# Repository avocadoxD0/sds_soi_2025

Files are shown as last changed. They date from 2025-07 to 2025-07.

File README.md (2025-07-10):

# Reaction Wheel Attitude Control System

This repository contains the complete design and development of a single-axis reaction wheel system for satellite attitude stabilization. The project brings together mechanical modeling, circuit design, and embedded control to achieve angular velocity detumbling.

The system is built around a reaction wheel mechanism, controlled using real-time feedback from an onboard IMU. All major subsystems including mechanical structure, electronics, and control algorithm are developed in coordination to function as a unified, self-contained system.

This repository serves as a consolidated record of the entire design process, including CAD models, PCB design files, and control code.

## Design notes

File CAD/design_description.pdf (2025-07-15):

## Design Decisions - Reaction Wheel Module

This reaction wheel system was designed to be compact, 3D-printable, and modular, suitable for integration into a CubeSat-class spacecraft. The following key design decisions were made:

- Volume Optimization:
The entire assembly was constrained to fit within a 60 mm x 60 mm x 69 mm housing, keeping the total volume under the specified 250 cm³
limit. This ensured compatibility with satellite form factor requirements.
- Flywheel Geometry:
A 50 mm diameter flywheel with 8 mm thickness was selected to maximize moment of inertia while ensuring adequate clearance within the enclosure. The flywheel was designed for uniform mass distribution and rotational balance.
- Gear-Based Torque Transmission:
A gear system was used between the DC motor and the flywheel shaft. A 10-tooth external gear drives a 24-tooth internal gear, resulting in torque amplification, ideal for generating controlled angular momentum.
- Motor Mounting and Axis Offset:
The DC motor is mounted 3.5 mm off-center to accommodate the gear mesh with the internal gear. The motor mount was custom-modeled to ensure tight fitment and structural rigidity, while allowing for proper shaft alignment.
- Material Selection:
All components were modeled using ABS plastic (as defined in SolidWorks), representing realistic 3D-printing material properties. This allowed accurate mass and inertia calculations throughout the design process.
- Printability Focus:
Every part was intentionally designed with minimal overhangs, greatly reducing the need for support structures during 3D printing. All geometries are primarily clean and self-supporting, ensuring straightforward and efficient fabrication.

This design prioritizes balance, printability, and functional performance, laying the groundwork for reliable attitude control when paired with embedded control logic and sensing systems.

## STL Orientation Note

The exported STL files are oriented in the Z-up direction, as defined during design in Solid-Works. While this orientation is consistent in both the CAD environment and GitHub STL previews, it is not necessarily optimized for 3D printing. Prior to printing, each part should be reoriented appropriately within slicing software such as Ultimaker Cura to ensure flat base surfaces and support-free printing. This adjustment is standard practice and ensures better printability without altering the model geometry.

1

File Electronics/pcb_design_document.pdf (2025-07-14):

# PCB Design Document

## Basics

The satellite power supply is assumed to be of 28 V. A buck converter has been used to

convert the voltage level to be within the acceptable limit for the choice of microcontroller

Arduino Nano. The LM2596S – 5 is used to obtain a 5 V DC supply from the satellite

power supply and this is used to power the Arduino Nano. The microcontroller has been

programmed with the control logic to operate the motor driver DRV8833PW.

## Further Details on Choice of Components

The motor driver DRV8833PW was selected to run a DC motor which was decided to

be the actuator. This uses MOSFETs which are much more efficient compared to the alternative Bipolar Junction Transistors (BJTs). They consume significantly less power

and is an optimal choice since power consumption and the resultant temperature rise is

of concern.

## PCB Layout

The area covered is much less than the limit of 10cm x 10cm. The components have been

arranged to aid in heat dissipation. There is a copper layer that acts as ground plane.

This also aids in heat dissipation helping to maintain the temperature in a sustainable

range by preventing overheating. The board will have 4 layers. This will help reduce the

lengths of traces as well. The placement of traces has been done to achieve a balance

between trace length and interference. There are also heat sinks for both the power

converter LM2596S - 5 as well as the motor driver DRV8833PW.

1

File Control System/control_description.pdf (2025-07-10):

## Reaction Wheel Control Code Description

### 1. Microcontroller

The control code is written for the Arduino Nano microcontroller. It communicates with the IMU over I²C and generates PWM signals to drive the motor through a DRV8833 H-bridge motor driver.

### 2. Sensors and Actuators

- Sensor: MPU9250 (9-axis IMU), using only the gyroscope’s Z-axis angular velocity for control feedback.
- Actuator: DC motor connected to a flywheel via an internal gear. The motor is controlled using the DRV8833 dual H-bridge motor driver, with PWM signals applied directly to the IN1 and IN2 pins.

### 3. Control System Behavior

The control system implements a PID controller to reduce angular velocity about the Z-axis. The current angular velocity is measured from the MPU9250 and compared to a small target threshold (approximately 0.5°/s, or 0.0087 rad/s). The resulting error is processed through the PID controller to determine the motor’s speed and direction.

### Behavior Under Different Conditions

- When the system starts with high angular velocity, the motor spins the flywheel in the opposite direction to apply counter-torque and reduce spin.
- As the angular velocity approaches the target value, the PWM duty cycle decreases and the motor slows down.
- Once the target is nearly reached, the system stabilizes and stops applying further corrections.

1

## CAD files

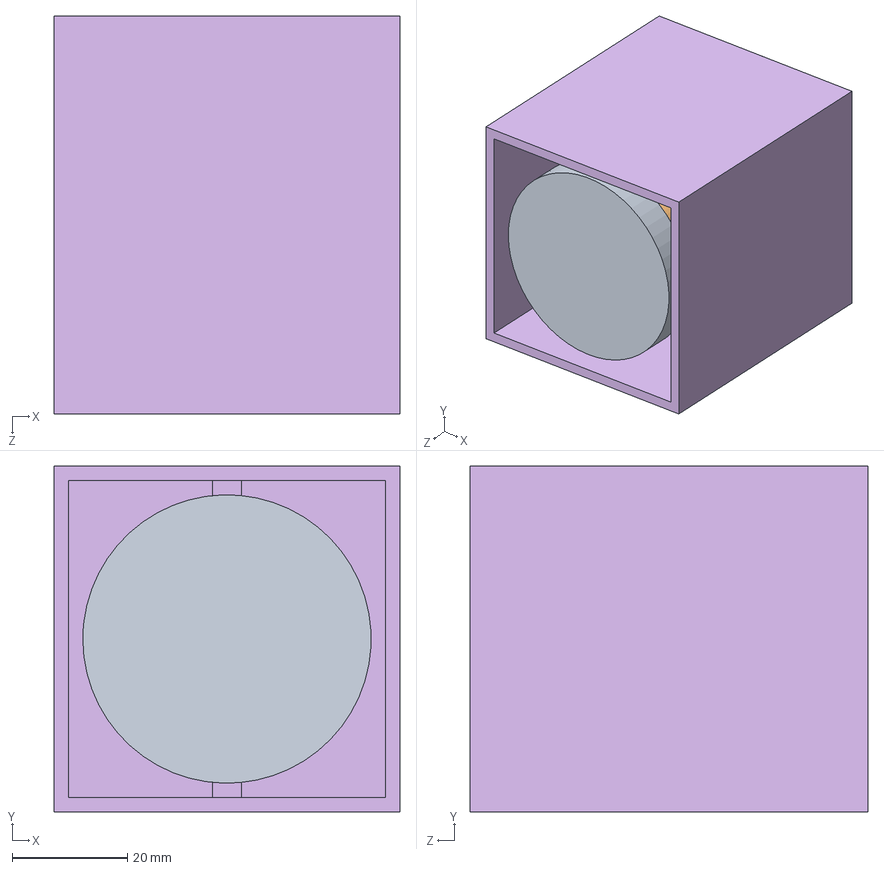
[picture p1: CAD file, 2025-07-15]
CAD/SOLIDWORKS_src/final assembly.SLDASM
60.0 x 60.0 x 69.0 mm
outer housing
motor mount
dc motor
motor gear
shaft
flywheel

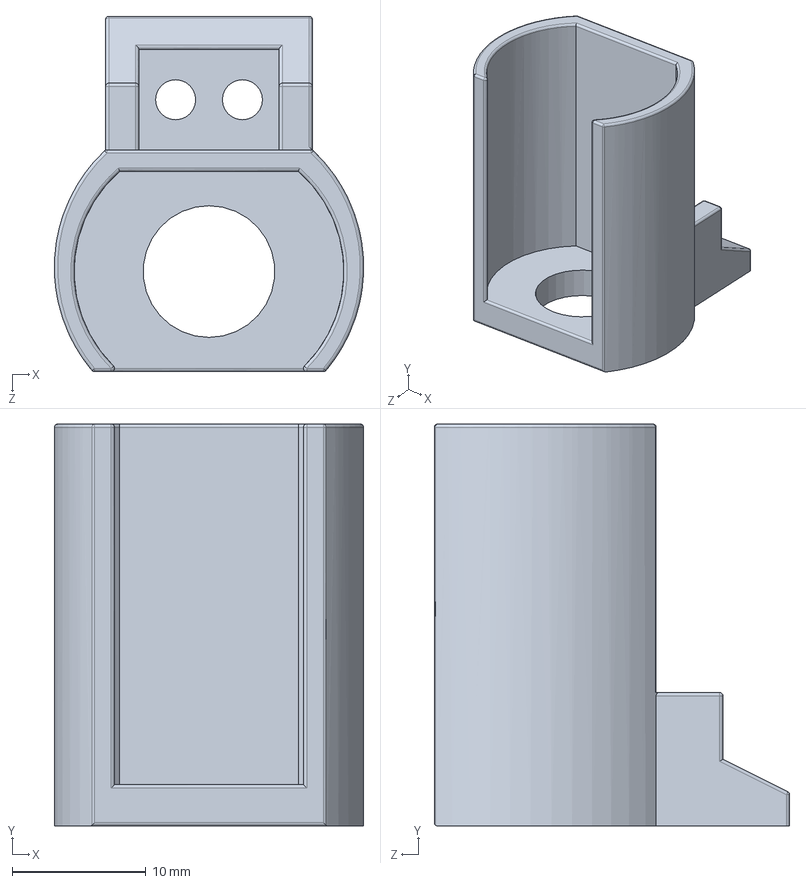
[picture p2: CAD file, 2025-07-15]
CAD/SOLIDWORKS_src/motor mount.SLDPRT
23.1 x 30.1 x 26.6 mm

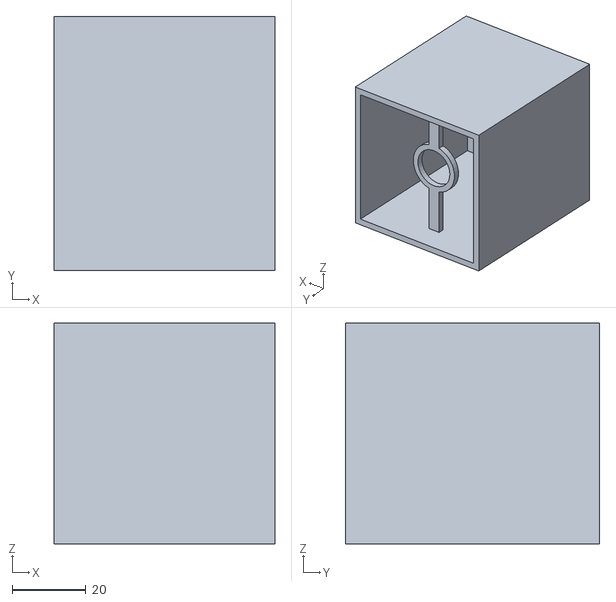
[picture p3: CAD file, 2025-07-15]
CAD/STL files/outer housing.STL
60.0 x 69.0 x 60.0

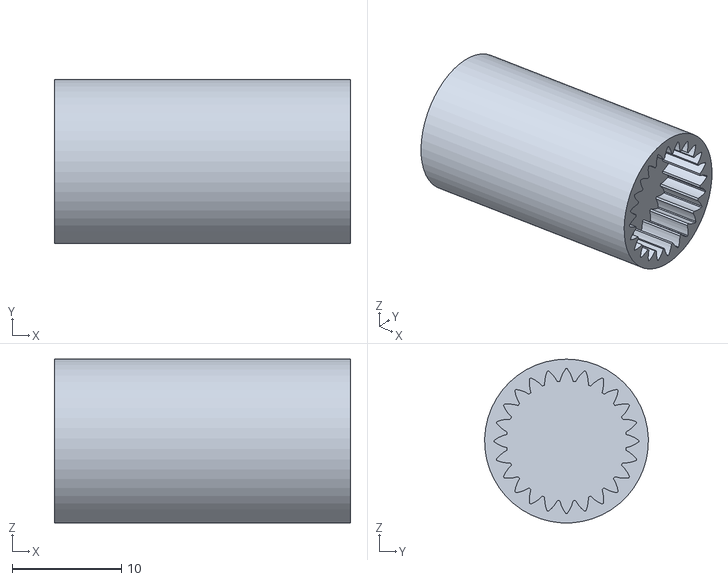
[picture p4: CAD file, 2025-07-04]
CAD/STL files/shaft.STL
27.1 x 15.0 x 15.0

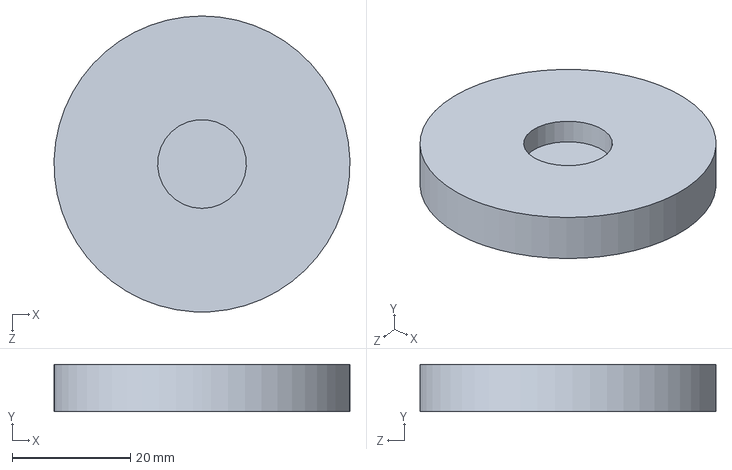
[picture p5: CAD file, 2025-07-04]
CAD/SOLIDWORKS_src/flywheel.SLDPRT
50.0 x 8.00 x 50.0 mm

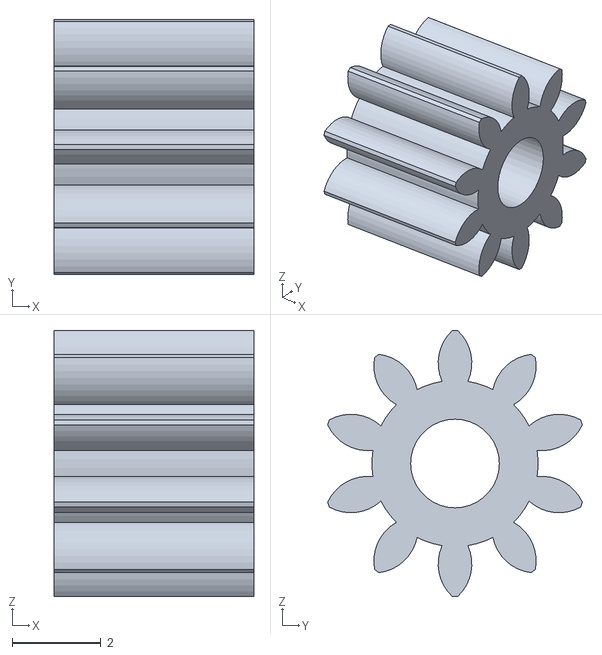
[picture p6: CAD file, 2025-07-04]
CAD/STL files/motor gear.STL
4.50 x 5.74 x 6.00

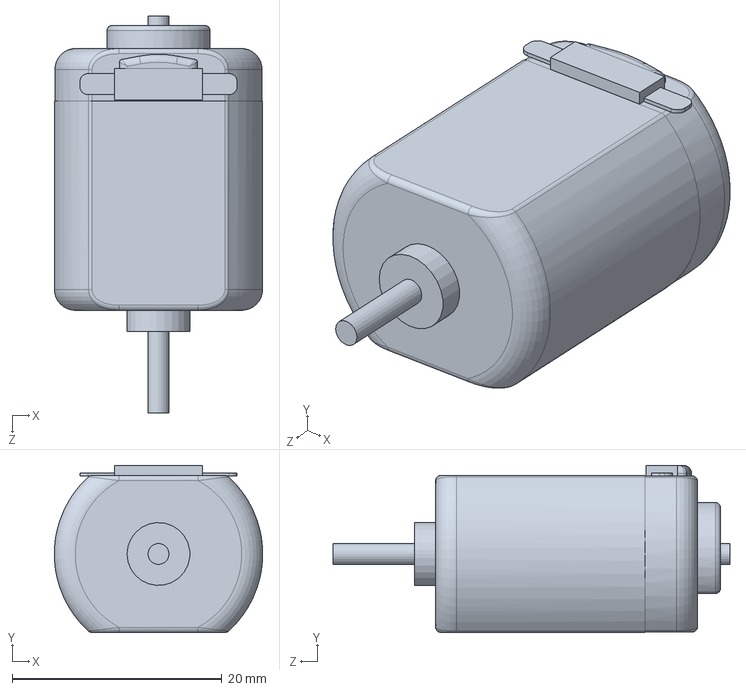
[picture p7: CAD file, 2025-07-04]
CAD/SOLIDWORKS_src/dc motor.SLDPRT
19.9 x 15.9 x 37.9 mm

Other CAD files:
CAD/STL files/motor mount.STL
CAD/SOLIDWORKS_src/outer housing.SLDPRT
CAD/SOLIDWORKS_src/motor gear.SLDPRT
CAD/STL files/flywheel.STL
CAD/SOLIDWORKS_src/shaft.SLDPRT

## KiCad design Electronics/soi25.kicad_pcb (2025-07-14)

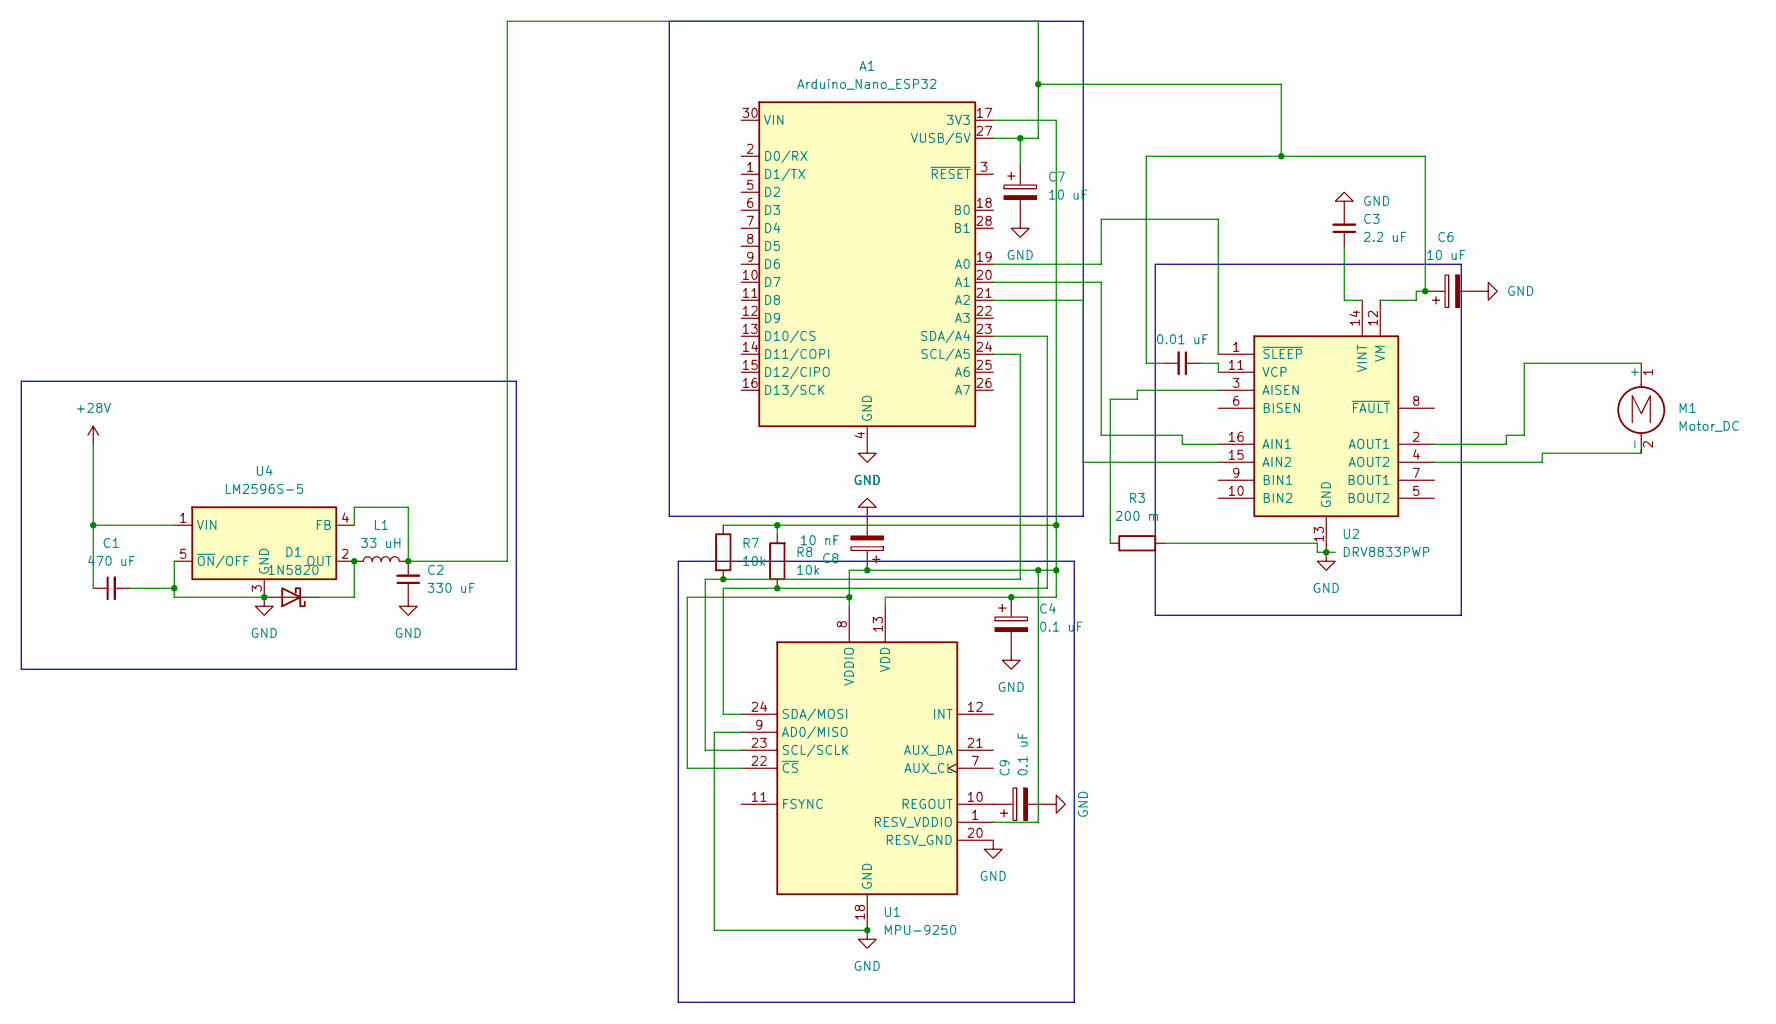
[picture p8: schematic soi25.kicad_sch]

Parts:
A1: Arduino_Nano_ESP32; Arduino_Nano
C1: 470 uF; C_Radial_D4.0mm_H5.0mm_P1.50mm
C2: 330 uF; C_Radial_D4.0mm_H5.0mm_P1.50mm
C3: 2.2 uF; C_0402_1005Metric_Pad0.74x0.62mm_HandSolder
C4, C9: 0.1 uF; C_0402_1005Metric_Pad0.74x0.62mm_HandSolder
C5: 0.01 uF; C_0402_1005Metric_Pad0.74x0.62mm_HandSolder
C6, C7: 10 uF; C_0402_1005Metric_Pad0.74x0.62mm_HandSolder
C8: 10 nF; C_0402_1005Metric_Pad0.74x0.62mm_HandSolder
D1: 1N5820; D_0201_0603Metric
L1: 33 uH; L_Wurth_WE-LQSH-2010
M1: Motor_DC; Vybronics_VZ30C1T8219732L
R3: 200 m; R_0402_1005Metric_Pad0.72x0.64mm_HandSolder
R7, R8: 10k; R_0402_1005Metric_Pad0.72x0.64mm_HandSolder
U1: MPU-9250; InvenSense_QFN-24_3x3mm_P0.4mm
U2: DRV8833PWP; HTSSOP-16-1EP_4.4x5mm_P0.65mm_EP3.4x5mm_Mask2.46x2.31mm_The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
U4: LM2596S-5; TO-263-5_TabPin3

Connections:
+28V: C1.1, U4.1 (VIN)
GND: A1.4 (GND), A1.29 (GND), C1.2, C2.1, C3.2, C4.2, C6.2, C7.2, C8.2, C9.2, D1.2 (A), R3.2, U1.9 (AD0/MISO), U1.18 (GND), U1.20 (RESV_GND), U2.13 (GND), U2.17 (GND), U4.3 (GND), U4.5 (~ON/OFF)
unnamed: A1.17 (3V3), C4.1, C8.1, R7.1, R8.2, U1.1 (RESV_VDDIO), U1.8 (VDDIO), U1.13 (VDD), U1.22 (~CS)
unnamed: A1.19 (A0), U2.1 (~SLEEP)
unnamed: A1.20 (A1), U2.16 (AIN1)
unnamed: A1.21 (A2), U2.15 (AIN2)
unnamed: A1.24 (SCL/A5), R7.2, U1.23 (SCL/SCLK)
unnamed: A1.23 (SDA/A4), R8.1, U1.24 (SDA/MOSI)
unnamed: A1.27 (VUSB/5V), C2.2, C5.2, C6.1, C7.1, L1.2, U2.12 (VM), U4.4 (FB)
unnamed: D1.1 (K), L1.1, U4.2 (OUT)
unnamed: M1.1 (+), U2.2 (AOUT1)
unnamed: M1.2 (-), U2.4 (AOUT2)
unnamed: C9.1, U1.10 (REGOUT)
unnamed: R3.1, U2.3 (AISEN)
unnamed: C5.1, U2.11 (VCP)
unnamed: C3.1, U2.14 (VINT)

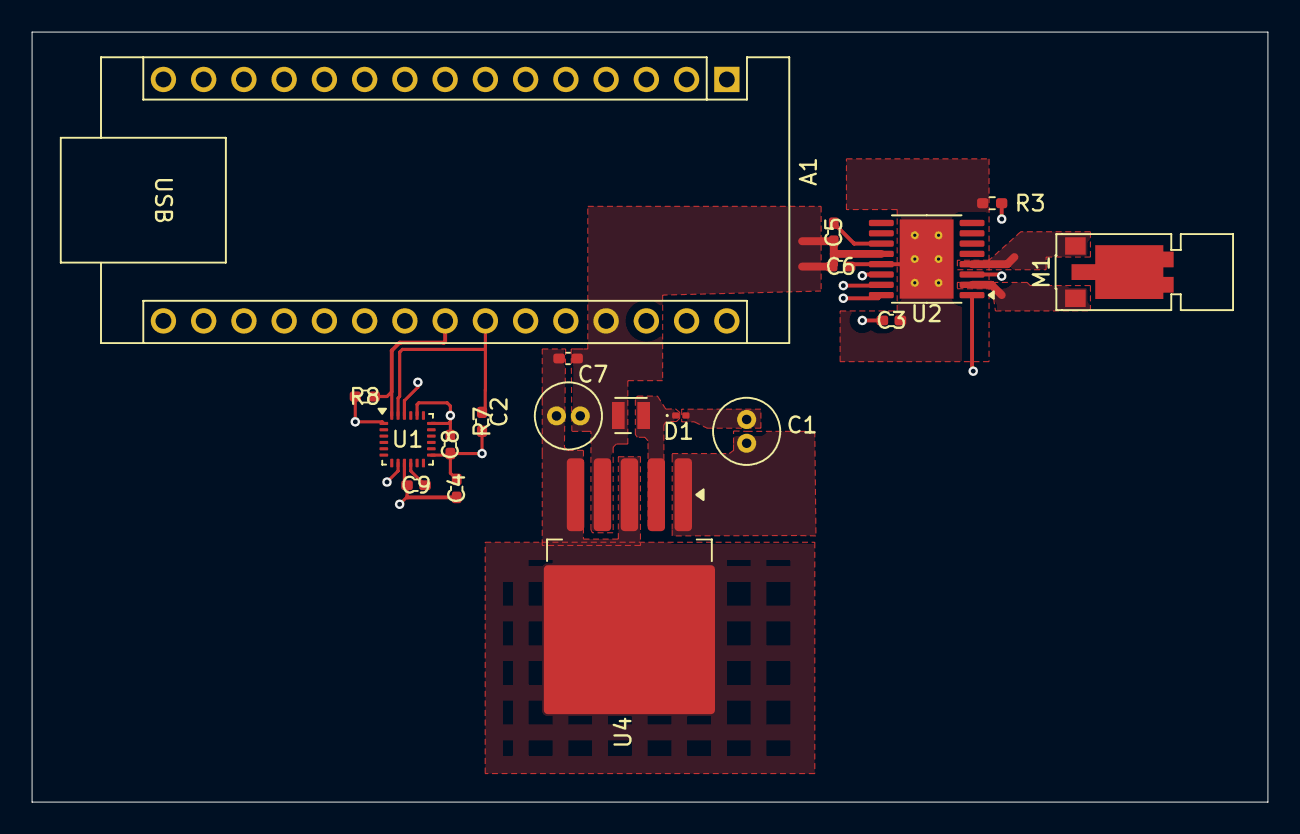
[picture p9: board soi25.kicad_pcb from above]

Board: 4 copper layers, 78.0 x 48.6 mm, 19 parts (0 on the bottom side), 16 nets.

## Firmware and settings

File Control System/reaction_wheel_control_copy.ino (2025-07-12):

/*
  Description:
  This code implements a PID-based angular velocity detumbling algorithm for a satellite
  using a reaction wheel. The MPU9250 provides angular velocity data, and a DC motor 
  is driven through a DRV8833 motor driver using PWM directly on the IN1 and IN2 pins.

  Microcontroller: Arduino Nano
  IMU Sensor: MPU9250 (I2C)
  Motor Driver: DRV8833
  Motor Type: DC Motor
  Control Mode: Angular Velocity Detumbling (Z-axis)
*/

#include <Wire.h>
#include <MPU9250_asukiaaa.h> // Install this library via Library Manager

MPU9250_asukiaaa mySensor;

// Pin definitions
const int IN1 = A1; // DRV8833 IN1 pin (PWM-capable)
const int IN2 = A2; // DRV8833 IN2 pin (PWM-capable)

// PID control variables
float Kp = 50.0;
float Ki = 0.5;
float Kd = 2.0;

float targetRate = 0.0087; // Target angular velocity (rad/s) ≈ 0.5 deg/s
float error = 0, prevError = 0;
float integral = 0;
float derivative = 0;
float pidOutput = 0;

// Timing
unsigned long lastTime = 0;
float dt = 0;

void setup() {
  Serial.begin(9600);
  Wire.begin();

  mySensor.setWire(&Wire);
  mySensor.beginAccel();
  mySensor.beginGyro();
  mySensor.beginMag();

  pinMode(IN1, OUTPUT);
  pinMode(IN2, OUTPUT);

  Serial.println("Reaction wheel control started.");
}

void loop() {
  // Read gyro data
  mySensor.accelUpdate();
  mySensor.gyroUpdate();
  float angularRateZ = mySensor.gyroZ(); // deg/s
  float angularRateZ_rad = radians(angularRateZ); // rad/s

  // Time step calculation
  unsigned long currentTime = millis();
  dt = (currentTime - lastTime) / 1000.0;
  if (dt <= 0) dt = 0.01; // prevent div by zero
  lastTime = currentTime;

  // PID control computation
  error = angularRateZ_rad - targetRate;
  integral += error * dt;
  derivative = (error - prevError) / dt;
  pidOutput = Kp * error + Ki * integral + Kd * derivative;
  prevError = error;

  // Convert PID output to PWM signal
  int pwmValue = constrain(abs(pidOutput) * 255, 0, 255);

  if (pidOutput > 0) {
    analogWrite(IN1, pwmValue); // Spin one direction
    digitalWrite(IN2, LOW);
  } else {
    digitalWrite(IN1, LOW);
    analogWrite(IN2, pwmValue); // Spin opposite direction
  }

  // Debug output
  Serial.print("ω (rad/s): ");
  Serial.print(angularRateZ_rad, 4);
  Serial.print(" | PWM: ");
  Serial.println(pwmValue);

  delay(20); // ~50 Hz control loop
}

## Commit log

2025-07-11 Schematic and PCB files
    [SoI.kicad_pcb, SoI.kicad_sch]
2025-07-11 PCB Explanation PDF
2025-07-14 Update the pcb and schematic
    [SoI.kicad_pcb, soi25.kicad_pcb, soi25.kicad_sch]
2025-07-14 Delete Electronics/pcb_design_document.pdf
    New version coming up
